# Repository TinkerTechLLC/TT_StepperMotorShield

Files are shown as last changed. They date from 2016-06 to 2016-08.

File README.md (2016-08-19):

# TT_StepperMotorShield
This stepper motor shield is capable of smooth, simultaneous control of two bi-polar stepper using [Allegro A4988 
stepper driver breakout sticks](https://www.pololu.com/product/1182). It also has a handy mounting location for an 
[XBee radio adapter board](https://www.adafruit.com/products/126). Use caution when using the XBee radio at the 
same time as the motors. It has been found to cause hiccups in the motors step interrupts, so this can cause the motors
to stall when running at higher speeds.

Order boards here: https://oshpark.com/shared_projects/M8zwapGA

Library for controller shield via Arduino Uno: https://github.com/TinkerTechLLC/TT_StepperMotorShield_Library

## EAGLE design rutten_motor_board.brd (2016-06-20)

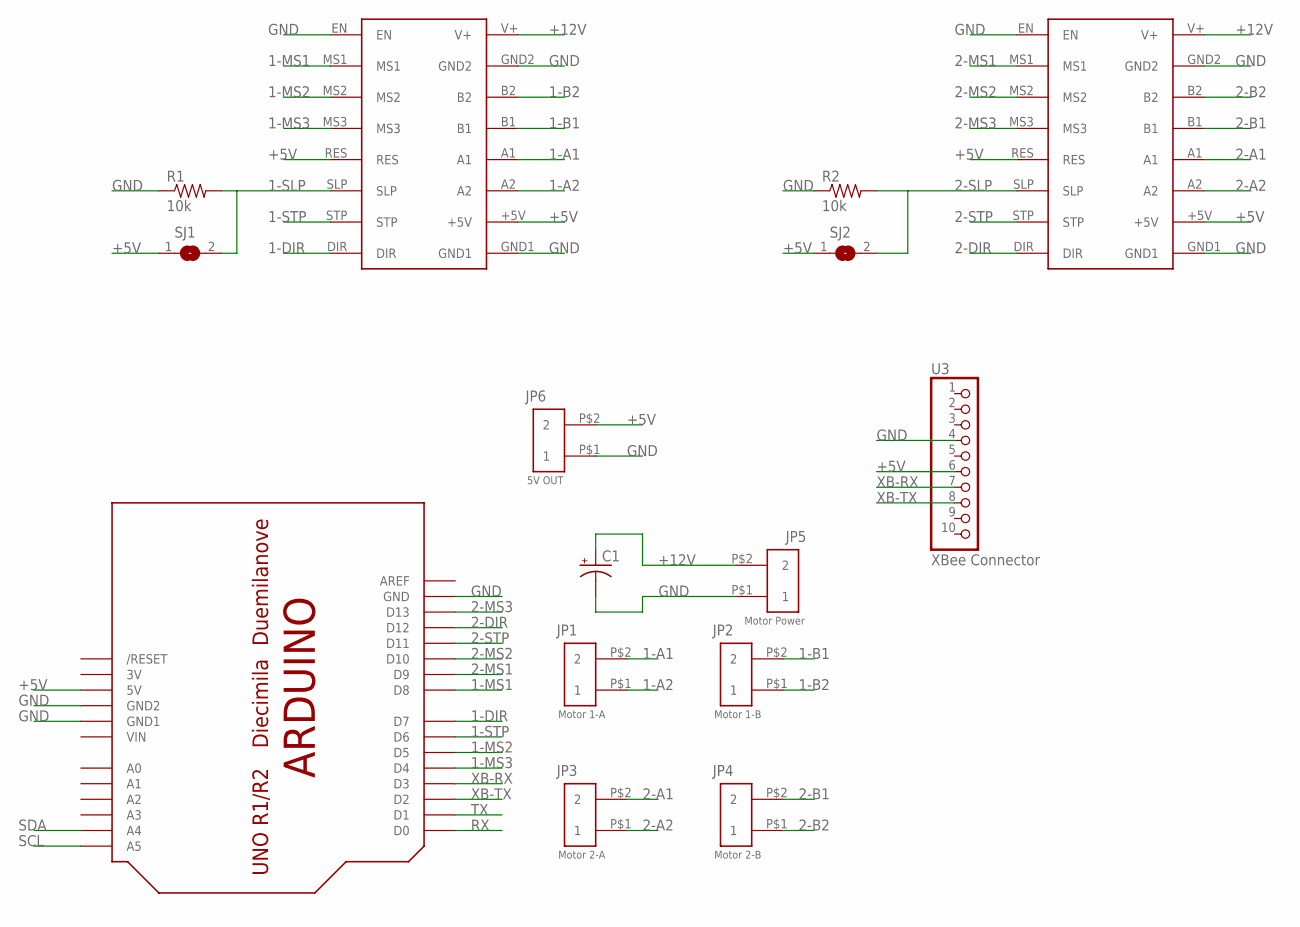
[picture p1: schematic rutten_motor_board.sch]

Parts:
C1: CAP_POLPTH2; CPOL-RADIAL-10UF-25V
JP1: Motor 1-A; SCREW_TERM-200MIL-2
JP2: Motor 1-B; SCREW_TERM-200MIL-2
JP3: Motor 2-A; SCREW_TERM-200MIL-2
JP4: Motor 2-B; SCREW_TERM-200MIL-2
JP5: Motor Power; SCREW_TERM-200MIL-2
JP6: 5V OUT; SCREW_TERM-200MIL-2
R1, R2: 10k; AXIAL-0.4
SJ1, SJ2: SJ
U1, U2: A4988_STEP_STICK; A9488_STEP_STICK
U3: XBee Connector; 1X10-BIG
U$1: ARDUINOUNO; ARDUINO

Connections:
1-A1: JP1.P$2 (2), U1.A1
1-A2: JP1.P$1 (1), U1.A2
1-B1: JP2.P$2 (2), U1.B1
1-B2: JP2.P$1 (1), U1.B2
1-DIR: U1.DIR, U$1.D7
1-MS1: U1.MS1, U$1.D8
1-MS2: U1.MS2, U$1.D5
1-MS3: U1.MS3, U$1.D4
1-SLP: R1.P$2 (2), SJ1.2, U1.SLP
1-STP: U1.STP, U$1.D6
2-A1: JP3.P$2 (2), U2.A1
2-A2: JP3.P$1 (1), U2.A2
2-B1: JP4.P$2 (2), U2.B1
2-B2: JP4.P$1 (1), U2.B2
2-DIR: U2.DIR, U$1.D12
2-MS1: U2.MS1, U$1.D9
2-MS2: U2.MS2, U$1.D10
2-MS3: U2.MS3, U$1.D13
2-SLP: R2.P$2 (2), SJ2.2, U2.SLP
2-STP: U2.STP, U$1.D11
5V: U$1.3V
+5V: JP6.P$2 (2), SJ1.1, SJ2.1, U1.+5V, U1.RES, U2.+5V, U2.RES, U3.6, U$1.5V
+12V: C1.1 (+), JP5.P$2 (2), U1.V+, U2.V+
GND: C1.2 (-), JP5.P$1 (1), JP6.P$1 (1), R1.P$1 (1), R2.P$1 (1), U1.EN, U1.GND1, U1.GND2, U2.EN, U2.GND1, U2.GND2, U3.4, U$1.GND, U$1.GND1, U$1.GND2
RX: U$1.D0
SCL: U$1.A5
SDA: U$1.A4
TX: U$1.D1
VIN: U$1.VIN
XB-RX: U3.7, U$1.D3
XB-TX: U3.8, U$1.D2

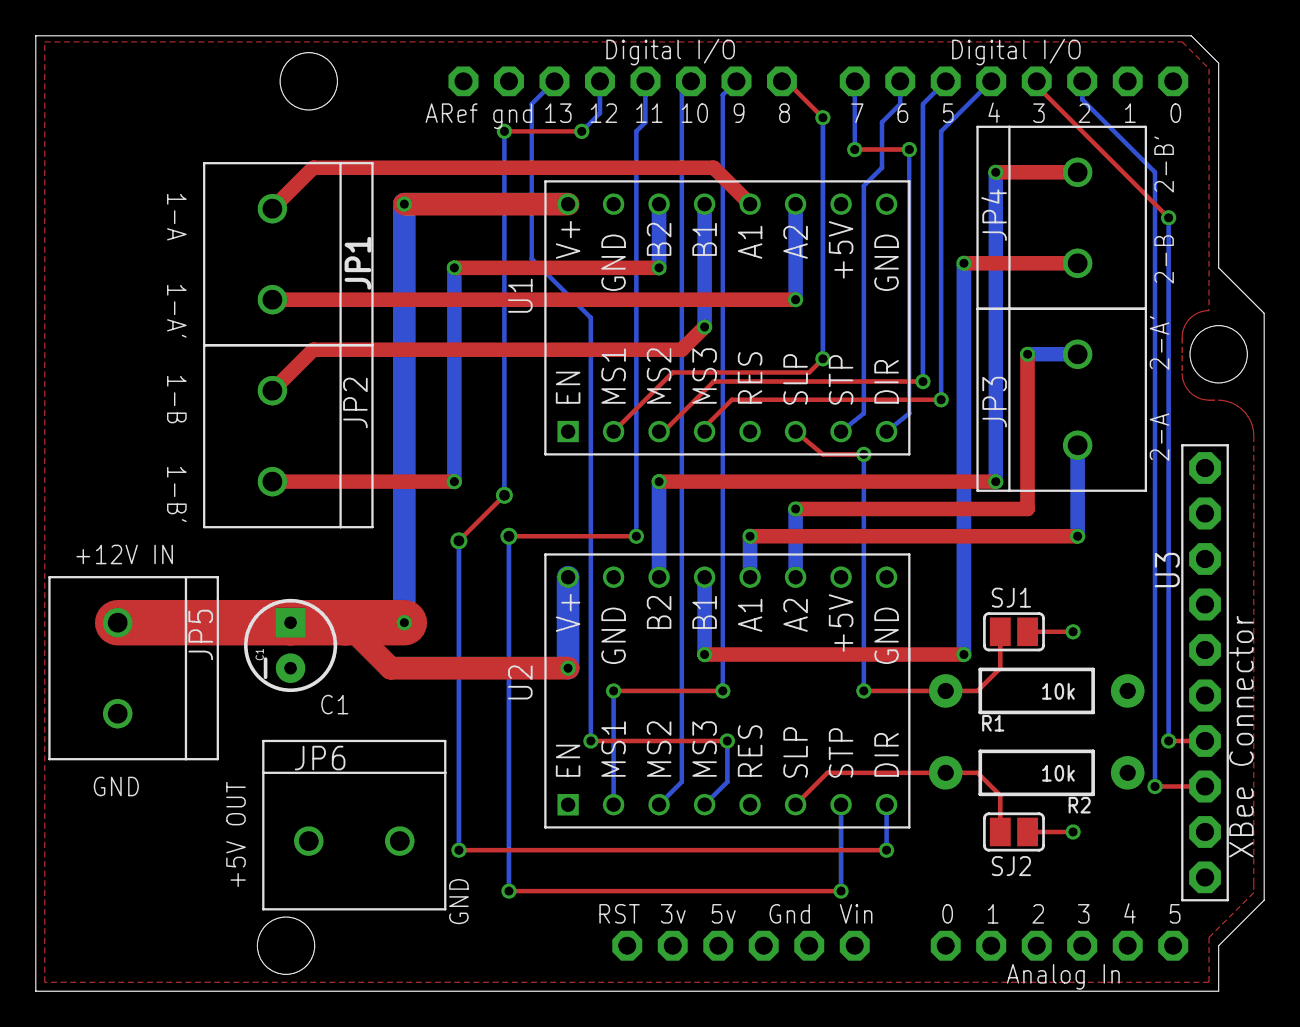
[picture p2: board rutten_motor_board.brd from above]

Board: 2 copper layers, 68.6 x 53.3 mm, 15 parts (0 on the bottom side), 25 nets.

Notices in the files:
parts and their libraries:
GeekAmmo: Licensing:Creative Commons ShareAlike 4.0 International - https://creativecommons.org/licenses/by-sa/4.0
